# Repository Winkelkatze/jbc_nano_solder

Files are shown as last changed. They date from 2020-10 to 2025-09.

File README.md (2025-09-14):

# JBC Nano Solder
DIY controller for JBC Nano (NT115) hand piece and C115 tips.

This project can be found on Hackaday: https://hackaday.io/project/175580-diy-jbc-nano-controller

JBC makes awesome high-end soldering irons for professional use. The stations are quite expensive (especially the Nano system), however the tips and hand pieces are reasonably priced for hobby users. Therefore building controllers for these became kind of a sport among DIYers.

## State of the project
This project is in a working state, but is not actively worked on and there are a few unsolved issues, that can lead to the tip overheating if things go wrong. The issues stem from using a low-side gate driver to drive a P-channel FET on the high side. This causes the default state to be **ON**, which in turn means, the heater is powered when there is no signal telling it otherwise. This happens, if the CPU is in RESET or has no power.
Make sure to always disconnect the iron when flashing the firmware, debugging or making changes to the hardware.
**As a mitigation, consider adding a pull-up resistor to the gate driver input.**

## Why Nano and not T245/T210 as everyone else?
The JBC NT115 soldering iron is amazing, it's quite compact, has a slim cable and the grip-to-tip distance is really small. It's meant for super fine-pitched SMT parts, yet if you combine it with a larger tip, its powerful enough for most soldering needs. So, despite being a high precision tool, it is still use-able as a general purpose soldering iron.

Also, there is no real point in DIYing a controller for the larger irons from scratch, since there are already heaps of projects on the internet.

## Differences to the T245/T210
Both have similar tips with the heater and thermocouple embedded directly in the tip.
### Plug
The most obvious difference is the plug, this immediately suggests that there are some more fundamental difference between the two irons.
### Voltage
The NT115 system is designed for a much lower voltage. If I remember correctly, NT115 uses about 9V while T245 is more 20ish. Not sure how bad too much power is, but overloading the tip by a factor of 4 doesn't sound good. For reference, the C115 heaters have a (hot) resistance of about 5 Ohms, which would result in ~16W at 9V, so that's quite close to the nominal 15W of the tips.
### Heater and thermocouple are in series
Despite the cable having three wires and the tip having three contacts, two of the contacts seem to be internally connected inside the tip. So, the only way to power the heater is through the thermocouple. This sounds odd at first, but that's just how it it...

## Status of this project
Everything works pretty well, the heat-up times are JBC-like fast and the temperature is quite stable. I don't know the exact characteristics of the thermocouple, but from tests, I assume the sensitivity is about 9uV/K. It doesn't matter that much, since the temperature you need for a job depends highly on the tip and the job anyway anyway. The hardware supports to measure the supply voltage, but I'm not using it right now.
### Under-voltage self destruct
One issue with the current hardware is a potential self-destruct scenario, if the supply voltage is too low. Since I'm using a low-side driver to drive a high-side P-Channel FET, the undervoltage lockout (about 4V) of the driver will force the FET ON when the supply voltage is too low. This may cause the tip or the mosfet to overheat. So, be careful with the choice of power supply.

## Building the firmware
To build the firmware, you will need the ARM toolchain on your machine. I have only tested the build on Linux, so not sure how this would work on other OSes.
### Clone repo and submodules
```
git clone https://github.com/Winkelkatze/jbc_nano_solder.git
cd jbc_nano_solder
git submodule init
git submodule update
```
### Build libopencm3
```
cd firmware/libopencm3
make
```
### Build the firmware
```
cd firmware
make
```
### Flashing the firmware
You can either use your preferred tool to flash the .elf manually or, if you have openocd installed and the controller connected with a STLINK, the firmware can be flashed with
```
make flash
```

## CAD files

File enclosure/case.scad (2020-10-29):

$fn=32;

mounting_cone_hole = 0.5;
mounting_cone_hole_depth = 4;
mounting_cone_r_top = 2;
mounting_cone_r_bottom = 3;
mounting_cone_height = 8;

mounting_holes = [
[25.9, 25.1],
[35.8, 25.1],
[67.6, 25.1],
[25.1, 47.0],
[40.6, 45.2],
[26.9, 68.3]];

encoder_pos = [30.2, 35.9];
encoder_hole_r = 3.5;

disp_cutout = [25.5, 9];
disp_pos = [11 + 3 + encoder_pos[0], encoder_pos[1] - 0.8 - disp_cutout[1]/2];

stand_nuts = [[63, 35], [73, 45]];
stand_nuts_hole = 1.5;
stand_nuts_extra_strength = 1;
stand_nuts_socket_height = 2.5;
stand_nuts_socket_size = 3.1;
stand_nuts_socket_brim = 2;

front_plate_width = 2;
sides_width = 2;
sides_height = 35;
sides_offset = front_plate_width;

pcb_offset = [22.9, 22.6];
pcb_size = [70.9, 71.6] - pcb_offset;
// top, right, bottom, left
pcb_spacing = [4, 30, 1, 1];

connector_holes = [
[10, 23, 7.5/2],
[35, 23, 10/2]];

bottom_overlap = 2.5;
bottom_height = 1.5;
bottom_overlap_width = 3;

holder_mount_distance = stand_nuts[1] - stand_nuts[0];
holder_base_size = 20;
holder_base_height = 10;
holder_base_wire = 0.4;
holder_tower_r = 4;
holder_tower_height = 85;
holder_tower_hole = 1.5;
holder_screw_offset = 2;
holder_screw_head = 2.8;

holder_arm_height = 9.5;
holder_arm_length = 30;
holder_arm_tower_overlap_r = 2;
holder_arm_tower_overlap_h = 6;
holder_arm_circle = 8;
holder_arm_circle_inner_t = 5.7;
holder_arm_hole = 4;
holder_arm_wire = 0.8;
holder_arm_wire_hor = 0.5;


outer_a = [
        -pcb_spacing[3] - sides_width,
        -pcb_spacing[0] - sides_width];
    
outer_size = [
    pcb_size[0] + pcb_spacing[3] + pcb_spacing[1] + sides_width * 2,
    pcb_size[1] + pcb_spacing[2] + pcb_spacing[0] + sides_width * 2];


module base_plate()
{
    translate([-pcb_spacing[3], -pcb_spacing[0], 0])
    {
        cube([
            pcb_size[0] + pcb_spacing[3] + pcb_spacing[1],
            pcb_size[1] + pcb_spacing[2] + pcb_spacing[0],
            front_plate_width]);
    }
}

module mountings()
{
    translate([-pcb_offset[0], -pcb_offset[1], front_plate_width])
    {
        for (hole = mounting_holes)
        {
            translate([hole[0], hole[1], 0])
            {
                difference()
                {
                    cylinder(mounting_cone_height,
                             mounting_cone_r_bottom,
                             mounting_cone_r_top);
                    translate([
                        0,
                        0,
                        mounting_cone_height - mounting_cone_hole_depth])
                    {
                        cylinder(mounting_cone_hole_depth,
                                 mounting_cone_hole,
                                 mounting_cone_hole);
                    }
                }
            }
        }
    }
}

module display_cutout()
{
    translate([-pcb_offset[0] + disp_pos[0],
               -pcb_offset[1] + disp_pos[1],
               0])
    {
        cube([disp_cutout[0],
              disp_cutout[1],
              front_plate_width]);
    }
}

module encoder_hole()
{
    translate([-pcb_offset[0] + encoder_pos[0],
               -pcb_offset[1] + encoder_pos[1],
               0])
    {
        cylinder(h=front_plate_width,
                 r1=encoder_hole_r,
                 r2=encoder_hole_r);
    }
}

module sides()
{
    translate([outer_a[0], outer_a[1], sides_offset])
    {
        cube([outer_size[0], sides_width, sides_height]);
        cube([sides_width, outer_size[1], sides_height]);
    }
    
    translate([outer_a[0], outer_a[1] + outer_size[1] - sides_width, sides_offset])
    {
        cube([outer_size[0], sides_width, sides_height]);
    }
    
    translate([outer_a[0] + outer_size[0] - sides_width, outer_a[1], sides_offset])
    {
        cube([sides_width, outer_size[1], sides_height]);
    }
}

module connector_holes()
{
    translate([outer_a[0] + outer_size[0] - sides_width, 0, front_plate_width])
    {
        for (hole = connector_holes)
        {
            translate([0, hole[0], hole[1]])
            {
                rotate([0,90,0])
                {
                    cylinder(sides_width, hole[2], hole[2]);
                }
            }
        }
    }
}

module stand_nuts_pos()
{
    for (s = stand_nuts)
    {
        translate([s[0], s[1], front_plate_width])
        {
            cylinder(h = stand_nuts_socket_height, r = stand_nuts_socket_size + stand_nuts_socket_brim + stand_nuts_extra_strength, $fn=6);
        }
    }
}

module stand_nuts_neg()
{
    for (s = stand_nuts)
    {
        translate([s[0], s[1], 0])
        {
            cylinder(h = front_plate_width + stand_nuts_extra_strength, r = stand_nuts_hole);
        }
        translate([s[0], s[1], front_plate_width + stand_nuts_extra_strength])
        {
            cylinder(h = stand_nuts_socket_height, r = stand_nuts_socket_size, $fn=6);
        }
    }
}

module base()
{
    hull()
    {
        base_plate();
        translate([outer_a[0], outer_a[1], sides_offset - 0.01])
        {
            cube([outer_size[0], outer_size[1], 0.01]);
        }
    }
}

module front_plate()
{
    difference()
    {
        union()
        {
            base();
            stand_nuts_pos();
        }
        display_cutout();
        encoder_hole();
        stand_nuts_neg();
    }
    
    
    mountings();
    difference()
    {
        sides();
        connector_holes();
    }
}

module bottom_plate()
{
    
    translate([-pcb_spacing[3], -pcb_spacing[0], 0])
    {
        difference()
        {
            cube([
                pcb_size[0] + pcb_spacing[3] + pcb_spacing[1],
                pcb_size[1] + pcb_spacing[2] + pcb_spacing[0],
                bottom_overlap]);
            translate([bottom_overlap_width, bottom_overlap_width, 0])
            {
                cube([
                pcb_size[0] + pcb_spacing[3] + pcb_spacing[1] - bottom_overlap_width * 2,
                pcb_size[1] + pcb_spacing[2] + pcb_spacing[0] - bottom_overlap_width * 2,
                bottom_overlap]);
            }
        }
    }
    
    translate([outer_a[0], outer_a[1], -bottom_height])
    {
        cube([outer_size[0], outer_size[1], bottom_height]);
    }
}

module holder_tower()
{
    hull()
    {
        cube([holder_base_size, holder_base_size, 0.01]);
        translate([holder_base_size / 2, holder_base_size / 2, holder_base_height])
        {
            cylinder(h=0.01, r=holder_tower_r);
        }
    }
    translate([holder_base_size / 2, holder_base_size / 2, holder_base_height])
    {
        cylinder(h=holder_tower_height, r=holder_tower_r);
    }
}

module holder_tower_neg()
{
    translate([holder_base_size / 2, holder_base_size / 2, 0])
    {
        cylinder(h=(holder_base_height + holder_tower_height), r=holder_tower_hole);
        translate([-holder_mount_distance[0] / 2, -holder_mount_distance[1] / 2, 0])
        {
            cylinder(h=holder_screw_offset, r=stand_nuts_hole);
            translate([0, 0, holder_screw_offset])
            {
                cylinder(h=holder_base_height, r=holder_screw_head);
            }
        }
        translate([holder_mount_distance[0] / 2, holder_mount_distance[1] / 2, 0])
        {
            cylinder(h=holder_screw_offset, r=stand_nuts_hole);
            translate([0, 0, holder_screw_offset])
            {
                cylinder(h=holder_base_height, r=holder_screw_head);
            }
            
            k = stand_nuts_hole / sqrt(2);
            translate([-k, -k, 0])
            {
                cylinder(h=holder_screw_offset, r=holder_base_wire);
            }
        }
        rotate([0, 90, 45])
        {
            cylinder(h=norm(holder_mount_distance / 2), r=holder_base_wire);
        }
    }
}

module holder()
{
    difference()
    {
        holder_tower();
        holder_tower_neg();
    }
}

module holder_arm_pos()
{
    hull()
    {
        cylinder(h=holder_arm_height, r=(holder_arm_tower_overlap_r + holder_tower_r));
        translate([holder_arm_length, 0, 0])
        {
            cylinder(h=holder_arm_height, r=holder_arm_circle);
        }
    }
}
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

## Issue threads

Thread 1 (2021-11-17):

question

hasulhasancevik, 2021-11-17:
hello, i want to try the project. I need help. Which compiler did you use? I tried cubemx and atollic but I'm getting a compile error.

Winkelkatze, 2021-11-17:
Indeed, there was an issue with the git submodules.
The issue should be fixed now and I added build instructions to the README.

Thanks for the feedback!

hasulhas, 2021-11-19:
Hello sir.  I added the new libraries, but I still get an error when compiling.  I guess I couldn't.  Is it possible to export the project again?  I am using stm32cubeid.

Winkelkatze, 2021-11-20:
I didn't use STM32CubeIDE or the STM32CubeMX for this project. Its built with libopencm3 and uses a Makefile for building. Not sure if its possible to build a plain Makefile project through the STM32CubeIDE.
But if you simply follow the build instructions you won't need the CubeIDE anyway.

hasulhas, 2021-11-20:
thank you very much for your help.  today i installed ubuntu program with virtual machine.  I created the *.elf file.  and I think it will be enough to write this file to the chip.

hasulhas, 2021-11-23:
Hello, I'm bothered again.  Does this project have auto sleep mode?

hasulhas, 2021-12-15:
Hello sir.  I built the circuit.  but the screen keeps coming and going.  and the encoder is not working.  What is the problem? can you help me?

https://user-images.githubusercontent.com/56305854/146142587-3e44a64a-28d1-4c33-b0aa-b25b265cdcbe.MOV

Winkelkatze, 2021-12-20:
This very much looks like a power supply issue. If you have one, you should check the 3.3V rail with an oscilloscope.

Have you connected a soldering iron in your test setup? Could be that the current draw brings the power supply to its knees.

hasulhas, 2021-12-21:
Thanks for your help.  screen problem solved.  but I could not run the encoder.  the opamp is connected but I did not power it.  I guess it's not related to that.  Sorry for tiring you.
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

https://user-images.githubusercontent.com/56305854/146919004-94443d6b-5d04-4af3-85bb-d3c4ca2760cd.MOV

Winkelkatze, 2021-12-21:
No worries :)
About the encoder: Not sure about that, but in the first video it looks like you accidentally swapped the encoder GND and 3.3V, this would explain why the switch is not working. Normally a press on the encoder *should* get you to the main screen.
If the encoder connections are correct and it still doesn't work, try to short PA6 to GND with a jumper wire.
About the rotary part, are you sure the encoder is a normal A/B encoder? On the PCB the pins are labeled as CLK and DT which suggest a different type of encoder.

hasulhas, 2021-12-21:
yes I tried without encoder.  with tweezers.  The menu did not come.  I guess I don't see a small detail :)

Winkelkatze, 2021-12-21:
Hmm, that's strange. The IOs for the encoder are pulled up by the micro using the internal pull-up resistors. So a very simple test would be to measure the voltage at these pins when there is nothing connected to them and the micro is running normally ("Default cfg loadad" screen on the display). If everything is working, your multimeter should read something between 2.5 and 3.3 volts.

If there is voltage on those pins, you could also try to measure the current sourced by them to verify the pull-up is working normally. Measuring in mA mode between the pin and GND should read about 100uA (0.1mA)

hasulhas, 2021-12-22:
Hello sir.  I made the measurements, it's on the 3.3v pa6 pin.  current 0.07mA.  There is an 8Mhz crystal on the circuit, is it normal?

Winkelkatze, 2021-12-22:
I just looked through the code. There is really not much that can go wrong between the screen you are stuck at and the main screen. Just to be sure, you connected the pin to ground *and* released it again, right? :)
One potential candidate would be the eeprom write never going through. Can you add a "return;" in source/eeprom_i2c.c at the beginning of eeprom_write (so in line 66)?

Besides that, do you have a serial adapter? The controller should be sending out some data on the TXD pin at 115200 baud. Might be helpful to see whats going on there

hasulhas, 2021-12-22:
sir, i am compiling via virtual drive for linux.  maybe there is an error.  Can you send the build.elf file?

Winkelkatze, 2021-12-23:
I doubt this is a problem with your toolchain, but I attached a build anyway. This also includes a build where the eeprom write is disabled. I also added some more debug output, so it would be very helpful, if you could check the serial output.
[firmware.zip](https://github.com/Winkelkatze/jbc_nano_solder/files/7769144/firmware.zip)

hasulhas, 2021-12-23:
thank you very much sir.  build.elf still didn't work but no eeprom.elf did.  As a result, is my eeprom incompatible?
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

Winkelkatze, 2021-12-23:
So it was a problem with the eeprom.
I re-checked my code and found some potential problems with the eeprom write routine. Can you try again with the new version?

hasulhas, 2021-12-24:
thank you sir.  the new build worked.  I'll try connecting a soldering iron.  I will let you know the latest.

hasulhas, 2021-12-24:
works great.  thank you very much.  excellent software and hardware.  How can I do the calibration?  It heats up to about 140 degrees low.  For example, I want to melt the solder at 180 degrees.

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

Winkelkatze, 2021-12-24:
It depends a bit on what handpiece / tip you are using. I designed that with the JBC nano tips in mind, which have a thermocouple sensitivity of about 9 uV/K. Most other soldering irons use thermocouples with a higher output voltage.

Minor changes can be compensated by changing the calibration value in the menu. The allowed range is 7.5-11uV/K. The limits for the range are hard-coded, but can be changed in the config.c file. You may would also have to change the PANIC_CUTOFF_ADC_VALUE (in main.c) to avoid the over-temperature shutdown (ERROR T HIGH).

But keep in mind, that the amplifier gain is set to work with these low-sensitivity thermocouples. The gain is 501, so this limits the maximum thermocouple voltage to about 6.5 mV. So for a different thermocouple you may have change the amplifier gain and also the value in the software.

hasulhas, 2022-01-21:
hello master.  The soldering iron was great, thank you very much.  Can you write a little code for me?  “1 second boot logo”

https://user-images.githubusercontent.com/56305854/150538077-2b62a775-fc5c-412c-9206-80cd500d1c95.MOV

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

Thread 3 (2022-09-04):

programing step

warehouseElc, 2022-09-04:
i want to ask about programing method you used,
what programing software and hardware. of course the OS are you using ?
i'm not familar with stm32, but i know the basic.

Winkelkatze, 2022-09-04:
This project runs on a STM32F030, this is one of the smallest (if not the smallest) STM32 controller. The software is based on libopencm3, which is a more compact alternative to the official CubeHAL from ST.

About the *how* I developed the firmware, I use the "classic" approach by using a text editor for writing code and a Makefile for compiling everything using the arm toolchain (arm-none-eabi-gcc). I've only tested this on Linux, but I might be possible to do the same thing with Cygwin or WSL on Windows.
The programmer itself is one of these cheap as STLink clones which I use together with OpenOCD. And sometimes I also use the embedded serial bootloader for flashing STM32.

warehouseElc, 2022-09-04:
thanks for replying my post, i just finish board assembley still waiting for handle and tip.
a bit confuse about selecting compiler, what should i buy ?
should it work with a generic stlink ?

if any exist video will help me very much. one more question, the At24cs01 is out of stock I can't find it, so i replace with at24c01, i confuse about pin a0,a1,a2 and i'm not connect it to anywhere.

Winkelkatze, 2022-09-05:
I don't know of any video to help you, but what you will need is the ARM toolchain (arm-none-eabi-gcc), git and make. I'm sure you can find install instructions for this on the internet.
Then you can simply follow the "Building the firmware" instructions from my README. This will produce a .elf file which can be flashed to the controller by various means. If you also install openocd it should be as simple as running "make flash" but there is also plenty information available how to get a .elf to your controller.

About the EEPORM, the at24c01 one should be fully compatible. I'm a bit confused about the address pins, did you change the footprint to a 8 pin variant? If so, the address pins need to be tied to ground. The 5 pin variant doesn't have these pins and they are bonded to ground internally.

warehouseElc, 2022-09-06:
i found some tutor in internet, hope that methode will working, first we need to compile to elf and secondly upload to the board right ?
is there any button i have to press before or during upload ?

i didnt make any changes of footprint, just making an adapter with protoboard and put in at oled pinout in series with oled display because it use same pinout i think it should work.

Winkelkatze, 2022-09-06:
Yes, its easiest to do this as two separate steps. For flashing, if you use the STLINK, you don't need to press any button.

If you decide to use the serial bootloader, you first need to bring the controller into the boor mode by holding the BOOT button while it starts. So press and hold boot while you also press RESET briefly. You can then use "stm32flash" (https://sourceforge.net/p/stm32flash/wiki/Home/) to write the firmware to the controller. If you choose this approach, don't forget to convert the .elf into binary first with "arm-none-eabi-objcopy -O binary firmware.elf firmware.bin".

Cool solution for the eeprom by the way :)

warehouseElc, 2022-09-06:
I think the first methode is more easy, i was install like you said and confirm that was a build.elf after i build the firmware. at openOCD command i test make flash and its says no stlink detect.
unfortunately i don't have stlink, maybe i'll buy a cheap clone one, so before thats arrive i still have a time to learn the firmware.

Winkelkatze, 2022-09-07:
Cool that it works so far.

About the buzzer, this should be possible since there is still about 600 bytes free.

warehouseElc, 2022-09-13:
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
update : its work but i dont know how to test eeprom, a bit confuse about datasheet at24c01n, some have address pin and the other said no internal conection. so i leave it open
any idea how to test it ?

Winkelkatze, 2022-09-14:
Nice board :)

About the EEPROM address pins, normally they should be tied to ground. But if it also works like this, they may have internal pull-downs so you could also let them floating. As long as its keeping the settings and the last set temperature, the eeprom is working fine.

Winkelkatze, 2022-09-14:
I just realized, that one value from the schematic was wrong. R5 should be 5K instead of 10K, to set the gain for the thermocouple to 501 (instead of the original 1001). I also added this value as a constant in main.c ("THERMOCOUPLE_GAIN").

If you don't have a 5k resistor at hand, you can just stack two 10k resistors, or use a slightly different value and adjust the THERMOCOUPLE_GAIN in main.c

warehouseElc, 2022-09-21:
today my Chinese 115 it has 3,1 ohm resistance.
it hot like it should. i didn't understand how the code works, i set to 110c it raise to 160c and go to 110. is it working correctly ?
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

Winkelkatze, 2022-09-21:
It should not do that. My build does not overshoot more than 5 degrees when turning on.
I see two possible causes for such behavior:

Cause 1: The outlier detection code for filtering the measured temperature is causing problems.
Maybe for some reason the temperature measurement in your setup is very noisy.
You can test that by adding a "return true;" to the first line of the "outlier_detection" function (Line 519 in main.c) The temperature control should still work like this, but the displayed temperature may be a bit unstable and the out-of-stand idle detection may not work.

Cause 2: The tip you are using has a much worse thermal coupling between the heater and the sensor.
All my tips react almost immediately to power changes. Meaning if the heater is turned OFF, the temperature immediately stops rising. It is possible, since you are using some non-original tips that the thermocouple lags behind the heater, which makes the control highly unstable. Increasing the "Reg wnd size" (In the Menu, in the "Heater controller" settings) to a higher value may help. This will slightly degrade the response to temperature changes though.

If you want to experiment with different control algorithms, the controller is implemented in "dma1_channel1_isr" (main.c)

warehouseElc, 2022-09-21:
thanks i'll try your guide.
oh yes forget to tell i was lazy to hook up with a good smps, so i connect it to linear ps, maybe that cause the trouble.

warehouseElc, 2022-09-22:
i think is not ps issue, like you said the noise is too high.

noise when start up.
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

noise when temp is stable.
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

Winkelkatze, 2022-09-24:
The only real way to solve that issue is by adjusting the controller. At the moment, the control algorithm is mainly a proportional approach with a small integral component.
I did it that way, since it worked perfectly for me. The tips you are using make the control more difficult, but I'm almost certain by implementing a proper PID control this could be solved.

Winkelkatze, 2022-09-24:
If you don't want to dig into controller design, I have a few alternative options for you which you might want to try:

Reducing the power limit ("Heater controller" -> "Max PWM duty") will definitely help.

You could try is to increase the P controllers window (Reg wnd size) even more and also increase the I controllers limit (Int. ofs limit). You need to adjust the limits in menu.c for that.
This makes the controller less aggressive which should solve overshooting.

One general remark though, even with the best control algorithms, the delay caused by the tip will always result in a slower response time and worse performance while soldering.

warehouseElc, 2022-09-24:
i already did incrase the pwm periode about 25ms and incrase the reg wnd size in main.c after the test yesterday, now no more over shoot, thanks for spending your time in this thread.
it's a great controller for nano and also good job for the hardware and software.
one issue with encoder, it jump 2 step
should it work if i fix debounce at input.c incrase or decrease the tick ?

Winkelkatze, 2022-09-26:
No, its a PI controller without differential (D) part. You are correct, that the "Int. ofs" (short for Integral offset) is the integral part. However, this is not implemented as a traditional P-I controller where P gets zero during stable operation. The 'I' part rather slightly offsets the target for the P controller so we reach the target.
But yes, "reg wnd size" (Regulation window size) sets the inverse gain for the P controller, so P = 1 / "reg wnd size".

About the encoder issue, seems like there are different types of encoders. The one I use makes two signal steps (phase changes) per physical / haptic step (detent). So that's why I implemented it this way. Maybe your encoder works differently. Could also be a contact bouncing issue, so you can also try to increase the debounce value.

warehouseElc, 2022-09-27:
now i get it, i've to calibrate with that way.

thanks, i'll try incrasing debounce value.
pin uart its for programing or debug ? or both function will work ? cause i didnt see any serial out at the firmware.

Closed 2022-11-28.

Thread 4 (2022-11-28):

improve with a buzzer

warehouseElc, 2022-11-28:
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

hello, i try to mod a firmware but i can't get it.
need help for my project  i still use Chinese c210 controller for this build, my plan is attach t-210 tips to this controller and i think it will work, just need to calibrate it.

what i need just a buzzer. the code is too complicated for me and i didn't know what pinout should use.
i didnt use uart port maybe you can change it to a buzzer for me if you're on a free hand, i'll be appreciated that.

Winkelkatze, 2022-12-07:
Sure, you could re-purpose the uart pins. They are even timer outputs, so this could be used to generate the waveform for the beeper (for those without inbuilt electronics).
Another option would be to leave out the crystal, since this is not exactly required in this application anyway. I just included that, since I always do :)

But, I honestly don't see any reason why a soldering controller would need a beeper...
So, I'm sorry, but if you want to have one, you have to implement it yourself. This should be really straight-forward by just reading a bit the libopencm3 documentation.

I could help you if you have any specific questions though :)

warehouseElc, 2022-12-08:
the reason why i need a buzzer is for feedback when its ready or error even it is on seat, because i cant always look to display when working on fragile component.
i try to implement it by myself, but i didn't test because i'm not sure will work, the timer confuse me a lot.

first i need to know, what timer in rx or tx pin can be used ?
i read in datasheet its run on different timer, should i use timer for that pin, or i can just used any timer available?

warehouseElc, 2022-12-20:
hello again,
today i was destroy my tip by disconnect the 3v supply and the mosfet stays on.
any idea how to force the mosfet off even no signal from mcu to the gate ? may be some pull down resistor i guess

hasulhas, 2024-01-10:
> hello again, today i was destroy my tip by disconnect the 3v supply and the mosfet stays on. any idea how to force the mosfet off even no signal to the gate ? may be some pull down resistor i guess

I had the same problem. Did you solve the problem?

warehouseElc, 2024-01-10:
nothing, just never cut any logic voltage. the way to turn on/off modul by cuting main voltage. now we have issue with over temp and the solder cool down.

hasulhas, 2024-01-11:
> nothing, just never cut any logic voltage. the way to turn on/off modul by cuting main voltage. now we have issue with over temp and the solder cool down.

added 10k resistor, between heater_on and VDC. problem solved.

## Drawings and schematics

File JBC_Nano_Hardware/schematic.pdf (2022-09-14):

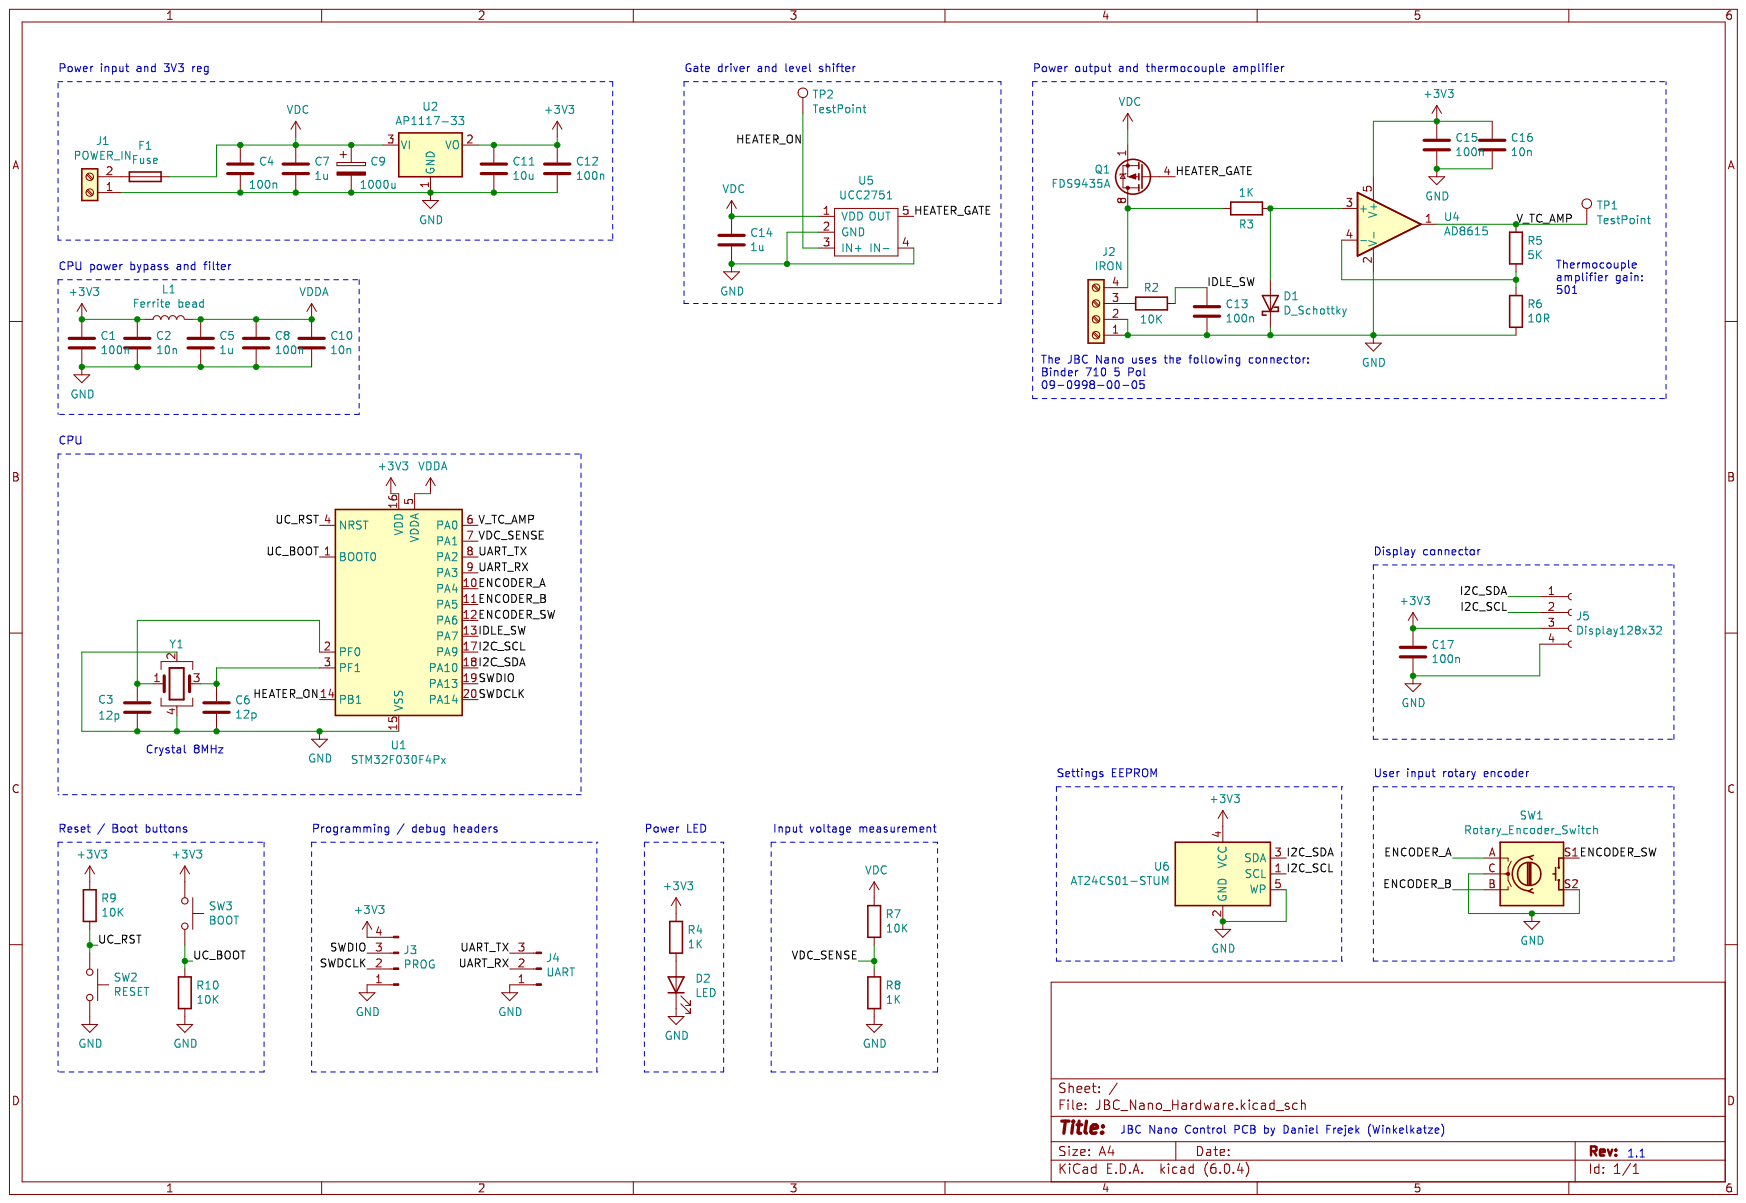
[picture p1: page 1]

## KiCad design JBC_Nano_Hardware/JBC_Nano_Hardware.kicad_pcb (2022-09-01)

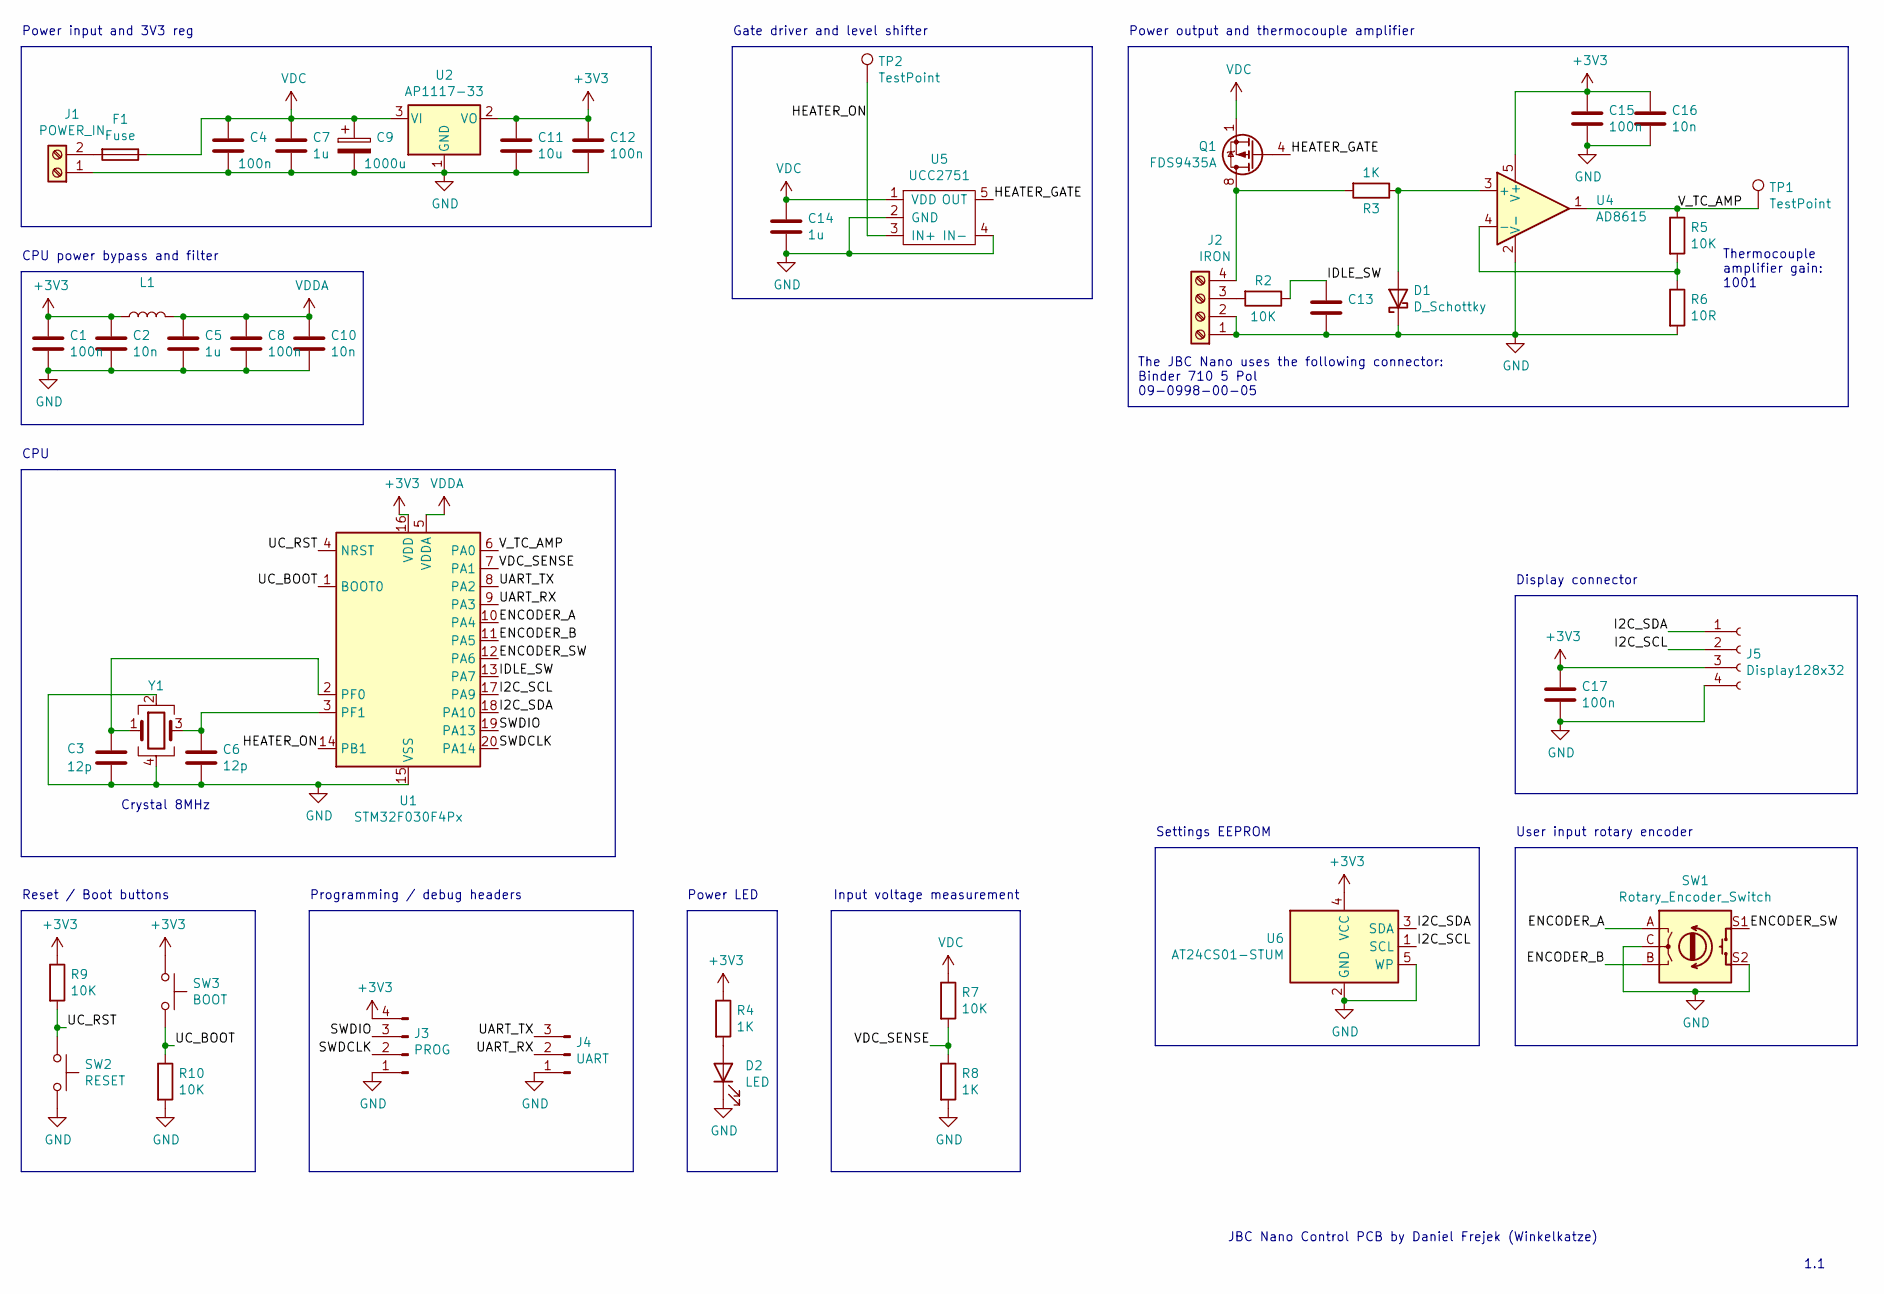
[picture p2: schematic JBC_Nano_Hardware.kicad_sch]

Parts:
C1, C4, C8, C12, C15, C17: 100n; C_0603_1608Metric
C2, C10, C16: 10n; C_0603_1608Metric
C3, C6: 12p; C_0603_1608Metric
C5, C7, C14: 1u; C_0603_1608Metric
C9: 1000u; CP_Radial_D10.0mm_P3.50mm
C11: 10u; C_0603_1608Metric
C13: C_0603_1608Metric
D1: D_Schottky; D_0603_1608Metric
D2: LED; LED_0603_1608Metric_Castellated
F1: Fuse; Fuseholder_Cylinder-5x20mm_Schurter_0031_8201_Horizontal_Op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
J1: POWER_IN; TerminalBlock_bornier-2_P5.08mm
J2: IRON; TerminalBlock_bornier-4_P5.08mm
J3: PROG; PinHeader_1x04_P2.54mm_Vertical
J4: UART; PinHeader_1x03_P2.54mm_Vertical
J5: Display128x32; PinSocket_1x04_P2.54mm_Vertical
L1: L_0805_2012Metric
Q1: FDS9435A; SOIC-8_3.9x4.9mm_P1.27mm
R2, R5, R7, R9, R10: 10K; R_0603_1608Metric
R3, R4, R8: 1K; R_0603_1608Metric
R6: 10R; R_0603_1608Metric
SW1: Rotary_Encoder_Switch; RotaryEncoder_Alps_EC12E-Switch_Vertical_H20mm
SW2: RESET; SW_SPST_B3U-1000P
SW3: BOOT; SW_SPST_B3U-1000P
TP1, TP2: TestPoint; TestPoint_Pad_D1.5mm
U1: STM32F030F4Px; TSSOP-20_4.4x6.5mm_P0.65mm
U2: AP1117-33; SOT-223-3_TabPin2
U4: AD8615; TSOT-23-5
U5: UCC2751; SOT-23-5
U6: AT24CS01-STUM; SOT-23-5
Y1: Crystal_GND24; Crystal_SMD_EuroQuartz_MJ-4Pin_5.0x3.2mm

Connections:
+3V3: C1.1, C2.1, C11.1, C12.1, C15.1, C16.1, C17.1, J3.4, J5.3, L1.1, R4.1, R9.1, SW3.1, U1.16 (VDD), U2.2 (VO), U4.5 (V+), U6.4 (VCC)
/ENCODER_A: SW1.A, U1.10 (PA4)
/ENCODER_B: SW1.B, U1.11 (PA5)
/ENCODER_SW: SW1.S1, U1.12 (PA6)
/HEATER_GATE: Q1.4 (G), U5.5 (OUT)
/HEATER_ON: TP2.1, U1.14 (PB1), U5.3 (IN+)
/I2C_SCL: J5.2, U1.17 (PA9), U6.1 (SCL)
/I2C_SDA: J5.1, U1.18 (PA10), U6.3 (SDA)
/IDLE_SW: C13.1, R2.1, U1.13 (PA7)
/SWDCLK: J3.2, U1.20 (PA14)
/SWDIO: J3.3, U1.19 (PA13)
/UART_RX: J4.2, U1.9 (PA3)
/UART_TX: J4.3, U1.8 (PA2)
/UC_BOOT: R10.1, SW3.2, U1.1 (BOOT0)
/UC_RST: R9.2, SW2.1, U1.4 (NRST)
/VDC_SENSE: R7.2, R8.1, U1.7 (PA1)
/V_TC_AMP: R5.1, TP1.1, U1.6 (PA0), U4.1
GND: C1.2, C2.2, C3.2, C4.2, C5.2, C6.2, C7.2, C8.2, C9.2, C10.2, C11.2, C12.2, C13.2, C14.2, C15.2, C16.2, C17.2, D1.1 (K), D2.1 (K), J1.1, J2.1, J2.2, J3.1, J4.1, J5.4, R6.2, R8.2, R10.2, SW1.C, SW1.S2, SW2.2, U1.15 (VSS), U2.1 (GND), U4.2 (V-), U5.2 (GND), U5.4 (IN-), U6.2 (GND), U6.5 (WP), Y1.2, Y1.4
unnamed: C3.1, U1.2 (PF0), Y1.1
unnamed: C6.1, U1.3 (PF1), Y1.3
unnamed: D1.2 (A), R3.1, U4.3 (+)
unnamed: D2.2 (A), R4.2
unnamed: F1.2, J1.2
unnamed: J2.3, R2.2
unnamed: J2.4, Q1.5 (D), Q1.6 (D), Q1.7 (D), Q1.8 (D), R3.2
unnamed: R5.2, R6.1, U4.4 (-)
VDC: C4.1, C7.1, C9.1, C14.1, F1.1, Q1.1 (S), Q1.2 (S), Q1.3 (S), R7.1, U2.3 (VI), U5.1 (VDD)
VDDA: C5.1, C8.1, C10.1, L1.2, U1.5 (VDDA)

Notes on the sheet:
Crystal 8MHz
JBC Nano Control PCB by Daniel Frejek (Winkelkatze)
Reset / Boot buttons
Gate driver and level shifter
CPU
Power LED
Power output and thermocouple amplifier
Thermocouple amplifier gain: 1001
1.1
Settings EEPROM
Input voltage measurement
CPU power bypass and filter
Programming / debug headers
Display connector
Power input and 3V3 reg
The JBC Nano uses the following connector: Binder 710 5 Pol 09-0998-00-05
User input rotary encoder

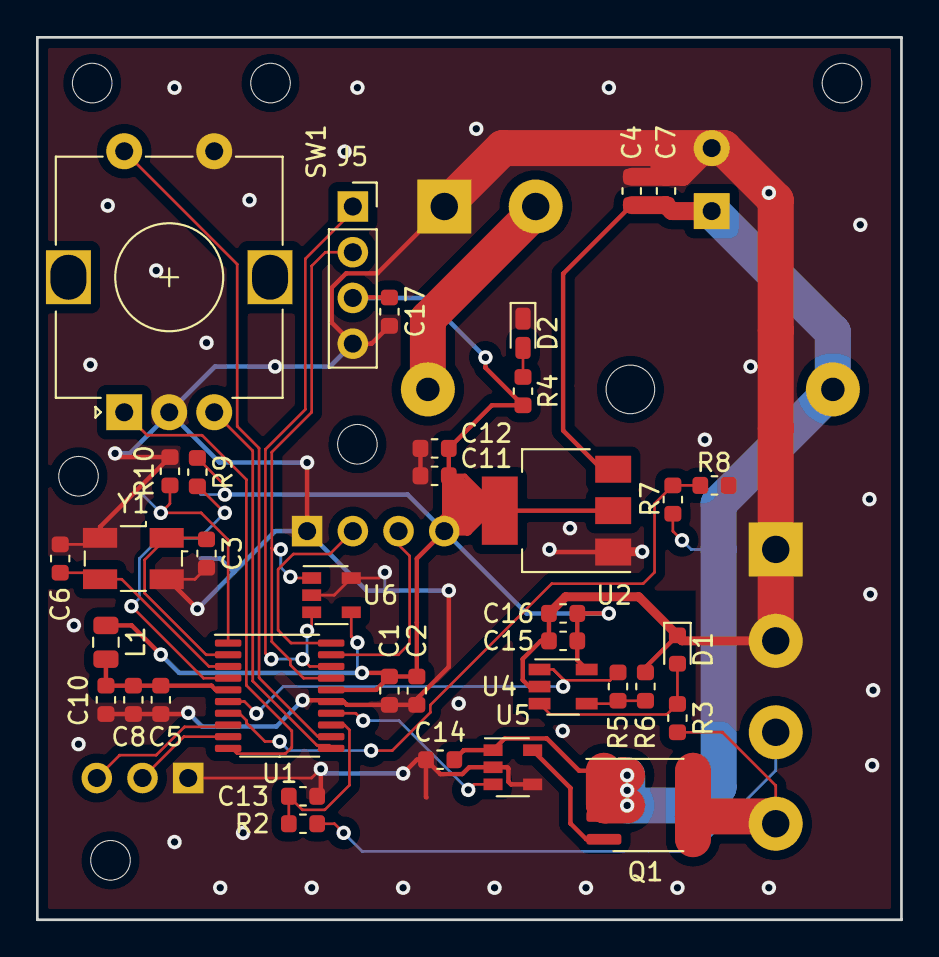
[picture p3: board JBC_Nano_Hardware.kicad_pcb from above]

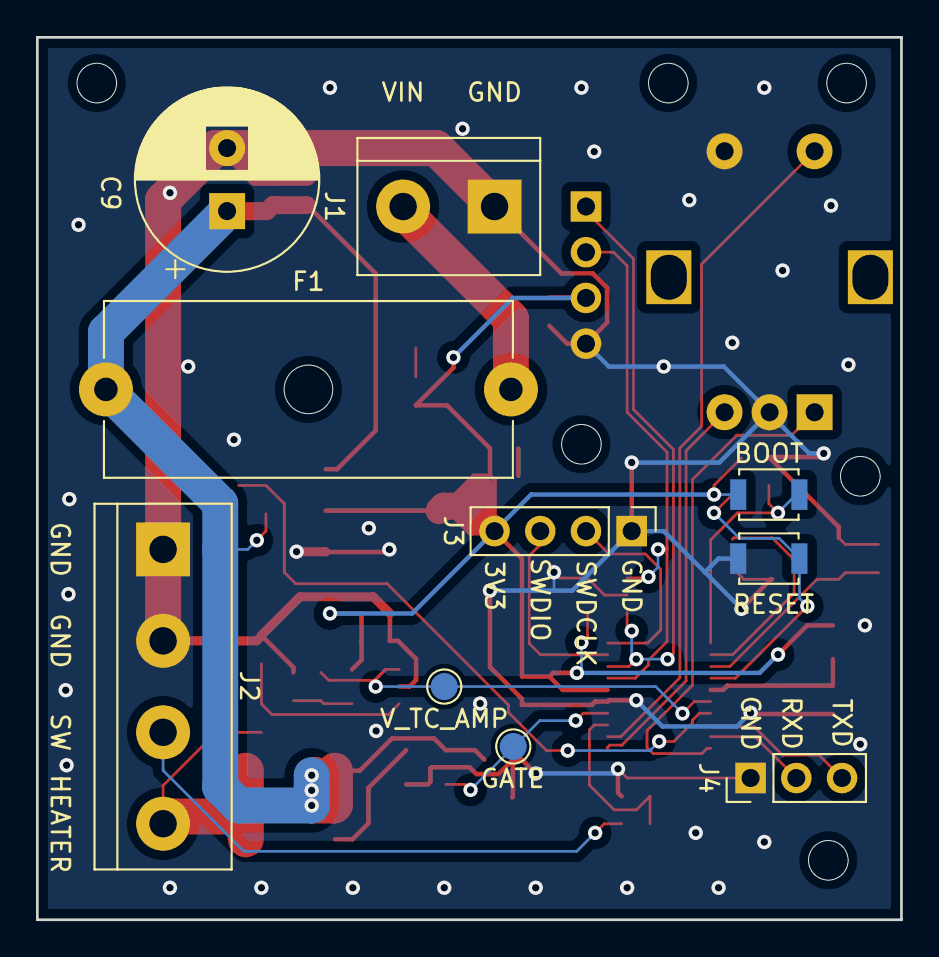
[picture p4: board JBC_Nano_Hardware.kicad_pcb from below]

Board: 2 copper layers, 48.0 x 49.0 mm, 47 parts (10 on the bottom side), 28 nets.

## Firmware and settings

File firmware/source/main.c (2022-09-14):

/*
 * MIT License
 *
 * Copyright (c) 2020 Daniel Frejek
 *
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
 * THE SOFTWARE IS PROVIDED "AS IS", WITHOUT WARRANTY OF ANY KIND, EXPRESS OR
 * IMPLIED, INCLUDING BUT NOT LIMITED TO THE WARRANTIES OF MERCHANTABILITY,
 * FITNESS FOR A PARTICULAR PURPOSE AND NONINFRINGEMENT. IN NO EVENT SHALL THE
 * AUTHORS OR COPYRIGHT HOLDERS BE LIABLE FOR ANY CLAIM, DAMAGES OR OTHER
 * LIABILITY, WHETHER IN AN ACTION OF CONTRACT, TORT OR OTHERWISE, ARISING FROM,
 * OUT OF OR IN CONNECTION WITH THE SOFTWARE OR THE USE OR OTHER DEALINGS IN THE
 * SOFTWARE.
 */

#include <libopencm3/stm32/rcc.h>
#include <libopencm3/stm32/gpio.h>
#include <libopencm3/stm32/usart.h>
#include <libopencm3/stm32/i2c.h>
#include <libopencm3/stm32/adc.h>
#include <libopencm3/stm32/dma.h>
#include <libopencm3/stm32/timer.h>
#include <libopencm3/stm32/iwdg.h>
#include <libopencm3/cm3/systick.h>
#include <libopencm3/cm3/nvic.h>
#include <libopencm3/stm32/exti.h>

#include <sys/types.h>
#include <stdlib.h>
#include <string.h>

#include "tinyprintf.h"
#include "ssd1306.h"
#include "eeprom_i2c.h"
#include "config.h"
#include "input.h"
#include "menu.h"
#include "gpio_conf.h"


#define HEATER_TIMER TIM3
#define HEATER_TIMER_PRESCALER 48 // 1us per tick, so max period is 65ms
#define HEATER_TIMER_OC TIM_OC4
#define HEATER_TIMER_OC_IRQ TIM_DIER_CC4IE

#define ADC_TRIGGER (3 << ADC_CFGR1_EXTSEL_SHIFT) // Timer3


// Gain of the thermocouple amplifier
#define THERMOCOUPLE_GAIN 501

#define TEMP_SAVE_INTERVAL 1000

// panic cutoff disables the heater until the mcu is reset
// this is at a relative temp of 440K assuming 9 uV/K and a VCC of 3.3V
#define PANIC_CUTOFF_ADC_VALUE ((440ULL * 9 * (THERMOCOUPLE_GAIN) * 4096) / 3300000) // ~430 C @ 3.3V

// Panic, if the temperature difference is below this for a given amount of time while the heater is on
// This should prevent overheating, if the tip is connected in the wrong polarity
#define PANIC_MINIMUM_TEMP_DIFF 20
#define PANIC_MINIMUM_TEMP_DIFF_TIMEOUT 1000

// If the measured supply voltage is not within this range, we set the error state
#define PANIC_MIN_SUPPLY_VOLTAGE  6000
#define PANIC_MAX_SUPPLY_VOLTAGE 15000

// Somehow we get some bad measurements (I think its interference from the display, but not sure...)
// In order to filter those, we add an "outlier detection"
// This works by calculating the average deviation from the average over the last measurements.
// If a measurement is more than THRESHOLD percent wrong, we skip controller cycle and use the average last value instead.
#define OUTLIER_DETECTION_WND 16
// Threshold should be at least 200, since this is what we expect for a monotonous increase
#define OUTLIER_DETECTION_THRESHOLD 230
// Minimum avg error (mK), this prevents generating lots of outliers when the temperature is stable
#define OUTLIER_DETECTION_MIN_AVG_ERR 2000

static void update_stby_state(void);
static bool outlier_detection(uint32_t value);

/*
 * Basic mode of operation
 * HEATING    |    DEAD_TIME    |    ADC_SAMPLE    | ...
 *            ^                 ^                  ^
 *        Timer OC   Timer update (adc trg)   ADC cplt int
 */

volatile uint32_t tickcounter = 0;


#define ADC_VALUE_VREF 0
#define ADC_VALUE_VDC  1
#define ADC_VALUE_TC   2
static volatile uint16_t adc_values[3];

// This is the panic shutdown
// Value is set to true, if the temperature exceeds the panic threshold
// It's never cleared, so device needs to be restart.
static volatile bool kill_heater = false;
static const char *err_reason = NULL;

// derived from period and max_pwm
static uint16_t heater_max_period;

static uint16_t temp_set;
static uint32_t temp_current1000;
static uint16_t controller_offset1000 = 0;
static uint32_t current_duty_smoothed = 0;
static uint32_t current_duty_lt_avg100 = 0;
static uint32_t temp_diff_panic_timer = 0;
static uint32_t outlier_detection_window[OUTLIER_DETECTION_WND] = {};
static size_t outlier_detection_index = 0;
static size_t outlier_detection_sum = 0;


static struct
{
	uint32_t idle_detect_timer;
	uint32_t timer;

	bool manual_off;
	bool off;
	bool stby;
	bool idle_sw;
} stby_state;



void sys_tick_handler(void)
{
	tickcounter++;
	input_update();
	update_stby_state();
}


void dma1_channel1_isr(void)
{
	// DMA interrupt from ADC DMA
	// only used for DMA1_TCIF
	dma_clear_interrupt_flags(DMA1, 1, DMA_TCIF);

	if (adc_values[ADC_VALUE_TC] > PANIC_CUTOFF_ADC_VALUE)
	{
		kill_heater = true;
		err_reason = "T HIGH";
	}

	uint16_t ts = temp_set;

	if (stby_state.off)
	{
		ts = 0;
	}
	else if (stby_state.stby && config.standby_temp < ts)
	{
		ts = config.standby_temp;
	}

	// thermocouple voltahe in 0.1uV
	uint32_t vtc_uv10 = (((33000000ULL / (THERMOCOUPLE_GAIN)) * ST_VREFINT_CAL) * adc_values[ADC_VALUE_TC]) / adc_values[ADC_VALUE_VREF] / 4096;

	// temperature in mK
	// Of course, our resolution isn't that high, but it makes our controller more stable if we use more precise values.
	uint32_t tc1000 = (1000 * vtc_uv10) / config.tc_v_per_deg;

	if (!kill_heater)
	{
		if (ts == 0 || tc1000 > PANIC_MINIMUM_TEMP_DIFF * 1000)
		{
			temp_diff_panic_timer = tickcounter;
		}
		else if ((tickcounter - temp_diff_panic_timer) > PANIC_MINIMUM_TEMP_DIFF_TIMEOUT)
		{
			kill_heater = true;
			err_reason = "T LOW";
		}

		uint32_t vdc = ((3300ULL * 11 * ST_VREFINT_CAL) * adc_values[ADC_VALUE_VDC]) / adc_values[ADC_VALUE_VREF] / 4096;
		if (vdc < PANIC_MIN_SUPPLY_VOLTAGE)
		{
			kill_heater = true;
			err_reason = "V LOW";
		}
		if (vdc > PANIC_MAX_SUPPLY_VOLTAGE)
		{
			kill_heater = true;
			err_reason = "V HIGH";
		}
	}

	tc1000 += config.tc_offset * 1000;

	uint16_t new_period = 0;

	// outlier detection
	if (outlier_detection(tc1000))
	{
		temp_current1000 = (temp_current1000 * 7 + tc1000) / 8;
		int err1000 = (int)(ts * 1000) - (int)tc1000;

		int int_adjust1000;
		if (err1000 > 0 && err1000 > config.controller_int_speed)
		{
			int_adjust1000 = config.controller_int_speed;
		}
		else if (err1000 < 0 && -err1000 > config.controller_int_speed)
		{
			int_adjust1000 = -(int)config.controller_int_speed;
		}
		else
		{
			int_adjust1000 = err1000;
		}

		if (int_adjust1000 > 0 && controller_offset1000 + int_adjust1000 > config.controller_int_limit * 1000)
		{
			controller_offset1000 = config.controller_int_limit * 1000;
		}
		else if (int_adjust1000 < 0 && controller_offset1000 < -int_adjust1000)
		{
			controller_offset1000 = 0;
		}
		else
		{
			controller_offset1000 += int_adjust1000;
		}

		err1000 += controller_offset1000;
		//printf("tc=%u, ts=%u, e=%i co=%u, ia=%i\n", tc1000/1000, temp_set, err1000, controller_offset1000, int_adjust1000);


		if (err1000 > config.controller_window * 1000)
		{
			// max power
			new_period = heater_max_period;
		}
		else if (err1000 > 0)
		{
			// (err / wnd) * max_period
			new_period = (err1000 * heater_max_period) / (config.controller_window * 1000);
		}
	}
	else if (!stby_state.off && ts > config.tc_offset)
	{
		// detected an outlier, so we just re-use the average
		new_period = current_duty_smoothed;
	}

	timer_set_oc_value(HEATER_TIMER, HEATER_TIMER_OC, new_period);

	current_duty_smoothed = ((current_duty_smoothed * 63) + new_period) >> 6;
	current_duty_lt_avg100 = ((current_duty_lt_avg100 * 1023) + (new_period * 100)) >> 10;

	//printf("s=%u c=%u err=%i period=%u period_max=%u\r\n", temp_set, temp_current, err, new_period, heater_max_period);

	// Re-arm adc trigger by setting the start bit
	adc_start_conversion_regular(ADC1);

	// Start the timer again
	timer_enable_counter(HEATER_TIMER);

	if (!kill_heater && new_period)
	{
		gpio_clear(GPIOB, GPIO_HEATER);
	}
}


void tim3_isr(void)
{
	// Only used for the OC interrupt
	// We should turn the heater OFF now
	timer_clear_flag(HEATER_TIMER, HEATER_TIMER_OC_IRQ);

	iwdg_reset();
	gpio_set(GPIOB, GPIO_HEATER);
}


static void tpf_putcf(void *ptr, char c)
{
	(void)ptr;
	usart_send_blocking(USART1, c);
}

static void clock_setup(void)
{
	rcc_clock_setup_in_hse_8mhz_out_48mhz();
	rcc_periph_clock_enable(RCC_GPIOA);
	rcc_periph_clock_enable(RCC_GPIOB);
	rcc_periph_clock_enable(RCC_USART1);
	rcc_periph_clock_enable(RCC_I2C1);
	rcc_periph_clock_enable(RCC_ADC1);
	rcc_periph_clock_enable(RCC_TIM3);
	rcc_periph_clock_enable(RCC_DMA);

	systick_set_frequency(1000, 48000000);
	systick_counter_enable();
	systick_interrupt_enable();
}


static void gpio_setup(void)
{
	// Timer output (On GPIOB !)
	// We do this first, since the heater is ON while the GPIO is floating!
	gpio_mode_setup(GPIOB, GPIO_MODE_OUTPUT, GPIO_PUPD_NONE, GPIO_HEATER);
	gpio_set_output_options(GPIOB, GPIO_OTYPE_PP, GPIO_OSPEED_HIGH, GPIO_HEATER);
	gpio_set(GPIOB, GPIO_HEATER);


	// USART
	gpio_mode_setup(GPIOA, GPIO_MODE_AF, GPIO_PUPD_NONE, GPIO2 | GPIO3);
	gpio_set_af(GPIOA, GPIO_AF1, GPIO2 | GPIO3);

	// I2C
	gpio_mode_setup(GPIOA, GPIO_MODE_AF, GPIO_PUPD_PULLUP, GPIO9 | GPIO10);
	gpio_set_output_options(GPIOA, GPIO_OTYPE_OD, GPIO_OSPEED_HIGH, GPIO9 | GPIO10);
	gpio_set_af(GPIOA, GPIO_AF4, GPIO9 | GPIO10);

	// ADC (V_TC and VDD)
	gpio_mode_setup(GPIOA, GPIO_MODE_ANALOG, GPIO_PUPD_NONE, GPIO0 | GPIO1);

	// Encoder and idle switch
	gpio_mode_setup(GPIOA, GPIO_MODE_INPUT, GPIO_PUPD_PULLUP, GPIO_ENCODER_A | GPIO_ENCODER_B | GPIO_ENCODER_SW | GPIO_IDLE_SW);
}


static void usart_setup(void)
{
	usart_set_baudrate(USART1, 115200);
	usart_set_databits(USART1, 8);
	usart_set_parity(USART1, USART_PARITY_NONE);
	usart_set_stopbits(USART1, USART_CR2_STOPBITS_1);
	usart_set_mode(USART1, USART_MODE_TX_RX);
	usart_set_flow_control(USART1, USART_FLOWCONTROL_NONE);

	usart_enable(USART1);
}


static void i2c_setup(void)
{
	rcc_set_i2c_clock_sysclk(I2C1);
	i2c_set_speed(I2C1, i2c_speed_fm_400k, 48);
	i2c_peripheral_enable(I2C1);
}


static void adc_setup(void)
{
	// The ADC will sample the TC voltage, VCC and the internal reference
	// TC conversion is last to maximize the time between turning off the heater and measuring the temp.
	// We configure the ADC in single-sequence mode tied to the haeter timer as trigger and the DMA in circular mode.
	// Then, a DMA_CPLT interrupt is generated after the full conversion is complete
	// To re-arm the ADC, we only need to set the start bit again.
	adc_calibrate(ADC1);
	adc_set_sample_time_on_all_channels(ADC1, ADC_SMPTIME_071DOT5);
	adc_enable_vrefint();
	uint8_t ADC_SEQUENCE[] = {ADC_CHANNEL_VREF, 1, 0};
	adc_set_regular_sequence(ADC1, sizeof(ADC_SEQUENCE) / sizeof(ADC_SEQUENCE[0]), ADC_SEQUENCE);
	adc_power_on(ADC1);
	adc_enable_dma(ADC1);
	adc_enable_external_trigger_regular(ADC1, ADC_TRIGGER, ADC_CFGR1_EXTEN_RISING_EDGE);
	//adc_enable_dma_circular_mode(ADC1);

	// setup DMA
	dma_set_memory_address(DMA1, DMA_CHANNEL1, (uint32_t)adc_values);
	dma_set_peripheral_address(DMA1, DMA_CHANNEL1, (uint32_t)&ADC1_DR);
	dma_set_memory_size(DMA1, DMA_CHANNEL1, DMA_CCR_MSIZE_16BIT);
	dma_set_peripheral_size(DMA1, DMA_CHANNEL1, DMA_CCR_PSIZE_16BIT);
	dma_enable_circular_mode(DMA1, DMA_CHANNEL1);
	dma_enable_memory_increment_mode(DMA1, DMA_CHANNEL1);
	dma_set_read_from_peripheral(DMA1, DMA_CHANNEL1);
	dma_enable_transfer_complete_interrupt(DMA1, DMA_CHANNEL1);
	dma_set_number_of_data(DMA1, DMA_CHANNEL1, sizeof(ADC_SEQUENCE) / sizeof(ADC_SEQUENCE[0]));
	dma_set_priority(DMA1, DMA_CHANNEL1, DMA_CCR_PL_HIGH);
	dma_set_channel_request(DMA1, DMA_CHANNEL1, 0);

	dma_enable_channel(DMA1, DMA_CHANNEL1);

	nvic_enable_irq(NVIC_DMA1_CHANNEL1_IRQ);

	// arm the adc trigger
	adc_start_conversion_regular(ADC1);
}


static void exti_setup(void)
{
	exti_select_source(EXTI_ENCODER_A | EXTI_ENCODER_SW | EXTI_IDLE_SW, GPIOA);
	exti_set_trigger(EXTI_ENCODER_A | EXTI_ENCODER_SW | EXTI_IDLE_SW, EXTI_TRIGGER_BOTH);
	exti_enable_request(EXTI_ENCODER_A | EXTI_ENCODER_SW | EXTI_IDLE_SW);

	nvic_enable_irq(NVIC_EXTI4_15_IRQ);
}


static void timer_setup(void)
{
	timer_set_mode(HEATER_TIMER, TIM_CR1_CKD_CK_INT, TIM_CR1_CMS_EDGE, TIM_CR1_DIR_UP);
	timer_set_prescaler(HEATER_TIMER, HEATER_TIMER_PRESCALER);
	timer_one_shot_mode(HEATER_TIMER);

	// for now we set the period to fixed 10ms
	timer_set_period(HEATER_TIMER, 10000);

	timer_set_master_mode(HEATER_TIMER, TIM_CR2_MMS_UPDATE);

	// instead of the OC output of the timer, we do it by foot through an interrupt
	// It's impossible to configure the OC output in a way, that the output stays in the same state as in the second half of the cycle
	timer_set_oc_value(HEATER_TIMER, HEATER_TIMER_OC, 0);
	timer_enable_irq(HEATER_TIMER, HEATER_TIMER_OC_IRQ);
	nvic_enable_irq(NVIC_TIM3_IRQ);
}


static void reset_stby_state(void)
{
	stby_state.timer = tickcounter;
	stby_state.idle_detect_timer = tickcounter;
	stby_state.idle_sw = input_idle_switch();
	stby_state.off = stby_state.manual_off;
	stby_state.stby = false;
}


static void update_stby_state(void)
{
	if (stby_state.manual_off)
	{
		stby_state.off = true;
		return;
	}

	if (!stby_state.off && config.idle_detect_threshold != 0)
	{
		// idle if long-term avg < current * (1 - threshold)
		if (current_duty_smoothed * (100 - config.idle_detect_threshold) > current_duty_lt_avg100)
		{
			// heater is doing things -> reset timer
			stby_state.idle_detect_timer = tickcounter;
		}
		else if (tickcounter - stby_state.idle_detect_timer > 60000UL * config.standby_time)
		{
			// idle detection timeout
			stby_state.off = true;
		}
	}

	if (input_idle_switch())
	{
		if (!stby_state.idle_sw)
		{
			stby_state.idle_sw = true;
			if (!stby_state.off)
			{
				// reset idle detect timer
				reset_stby_state();
			}
		}
		if (stby_state.off)
		{
			return;
		}

		if (stby_state.stby && tickcounter - stby_state.timer > 60000UL * config.standby_time)
		{
			// standby timeout -> turn off
			stby_state.off = true;
		}

		if (!stby_state.stby && tickcounter - stby_state.timer > 10000UL * config.standby_delay)
		{
			// not yet in standby and long enough in holder
			stby_state.stby = true;
			stby_state.timer = tickcounter;
		}
	}
	else
	{
		// NOT in holder
		if (stby_state.idle_sw)
		{
			// reset idle detect timer
			reset_stby_state();
		}
	}
}


static void update_config(void)
{
	timer_set_period(HEATER_TIMER, config.controller_period * 1000);
	heater_max_period = (((uint32_t)config.controller_max_pwm) * config.controller_period * 1000) / 100;

	if (temp_set < config.limit_min)
	{
		temp_set = config.limit_min;
	}
	if (temp_set > config.limit_max)
	{
		temp_set = config.limit_max;
	}

	config_save();
}


static bool outlier_detection(uint32_t value)
{
	// insert new value
	outlier_detection_sum -= outlier_detection_window[outlier_detection_index];
	outlier_detection_window[outlier_detection_index] = value;
	outlier_detection_index = (outlier_detection_index + 1) % OUTLIER_DETECTION_WND;
	outlier_detection_sum += value;

	uint32_t avg = outlier_detection_sum / OUTLIER_DETECTION_WND;

	uint32_t err_sum = 0;
	for (size_t i = 0; i < OUTLIER_DETECTION_WND; ++i)
	{
		if (outlier_detection_window[i] > avg)
		{
			err_sum += outlier_detection_window[i] - avg;
		}
		else
		{
			err_sum += avg - outlier_detection_window[i];
		}
	}

	uint32_t avg_err = err_sum / OUTLIER_DETECTION_WND;
	if (avg_err < OUTLIER_DETECTION_MIN_AVG_ERR)
	{
		avg_err = OUTLIER_DETECTION_MIN_AVG_ERR;
	}

	uint32_t val_err;
	if (value > avg)
	{
		val_err = value - avg;
	}
	else
	{
		val_err = avg - value;
	}

	return val_err * 100 < avg_err * OUTLIER_DETECTION_THRESHOLD;
}


static void screen_home(void)
{
	uint32_t sw_dn = 0;
	char disp_buf[32];
	uint32_t temp_changed_time;
	bool temp_changed = false;
	while (1)
	{
		uint16_t temp_round = (((temp_current1000 / 1000) + 2) / 5) * 5;
		//uint16_t temp_round = temp_current1000 / 1000;

		ssd1306_Fill(Black);
		ssd1306_SetCursor(0, 3);
		disp_buf[0] = ' ' + ((temp_round / 100) % 10);
		disp_buf[1] = ' ' + ((temp_round / 10 ) % 10);
		disp_buf[2] = ' ' + ((temp_round      ) % 10);
		disp_buf[3] = 0;

		ssd1306_WriteStringComp(disp_buf, CompFont_16x26_NUMC, White);
		ssd1306_DrawCircle(54, 10, 3, White);
		ssd1306_SetCursor(58,3);
		ssd1306_WriteStringComp("\x2a", CompFont_16x26_NUMC, White);

		ssd1306_SetCursor(90,3);
		snprintf(disp_buf, sizeof(disp_buf), "%3u", temp_set);
		ssd1306_WriteStringComp(disp_buf, CompFont_7x10, White);
		ssd1306_DrawCircle(117, 5, 1, White);
		ssd1306_SetCursor(121, 3);
		ssd1306_WriteStringComp("C", CompFont_7x10, White);

		if (kill_heater)
		{
			ssd1306_SetCursor(128 - 6 * 7,12);
			ssd1306_WriteStringComp("ERROR ", CompFont_7x10, Black);

			if (err_reason)
			{
				ssd1306_SetCursor(128 - 6 * 7,22);
				ssd1306_WriteStringComp(err_reason, CompFont_7x10, Black);
			}
		}
		else if (stby_state.off)
		{
			ssd1306_SetCursor(128 - 3 * 7,22);
			ssd1306_WriteStringComp("OFF", CompFont_7x10, White);
		}
		else if (stby_state.stby)
		{
			ssd1306_SetCursor(128 - 4 * 7,22);
			ssd1306_WriteStringComp("STBY", CompFont_7x10, White);
		}
		else
		{
			ssd1306_SetCursor(128 - 2 * 7,22);
			ssd1306_WriteStringComp("ON", CompFont_7x10, White);
		}

		uint16_t pwrline = current_duty_smoothed * 128 / heater_max_period;

		if (pwrline)
		{
			ssd1306_Line(0, 31, pwrline, 31, White);
		}

		ssd1306_UpdateScreen();


		printf("c=%lu, lt=%lu, idle=%lu\r\n", current_duty_smoothed, current_duty_lt_avg100, tickcounter - stby_state.idle_detect_timer);
		//printf("t_min=%i, tmax=%i, v33min=%i, v33max=%i\r\n", adc_tc_min, adc_tc_max, adc_v33_min, adc_v33_max);


		// update every 100 ms
		input_delay_or_evt(100);
		if (input_encoder_switch())
		{
			if (sw_dn == 0)
			{
				sw_dn = tickcounter;
			}
			else if (tickcounter - sw_dn > 1000)
			{
				// Long press -> Menu
				return;
			}
		}
		else if (sw_dn != 0)
		{
			sw_dn = 0;
			// Short press -> On/Off

			// We set the manual off state here to the inverse of the off state.
			// Otherwise (using the manual_state) pressing the switch while OFF from idle will turn the iron OFF first.
			stby_state.manual_off = !stby_state.off;
			reset_stby_state();
		}

		uint16_t old_temp = temp_set;
		temp_set = input_add_encoder_value_bound_step((temp_set * 5) / 5, config.limit_min, config.limit_max, 5);

		if (temp_set != old_temp)
		{
			temp_changed = true;
			temp_changed_time = tickcounter;
		}

		if (temp_changed && tickcounter - temp_changed_time > TEMP_SAVE_INTERVAL)
		{
			printf("Saving new temp: %u/r/n", temp_set);
			config_set_last_temperature(temp_set);
			temp_changed = false;
		}
	}
}


static void screen_raw(void)
{
	while (!input_encoder_switch())
	{
		uint32_t v33 = (3300 * ST_VREFINT_CAL) / adc_values[ADC_VALUE_VREF];
		uint32_t vdc = ((3300ULL * 11 * ST_VREFINT_CAL) * adc_values[ADC_VALUE_VDC]) / adc_values[ADC_VALUE_VREF] / 4096;
		uint32_t vtc = (((3300000ULL / (THERMOCOUPLE_GAIN)) * ST_VREFINT_CAL) * adc_values[ADC_VALUE_TC]) / adc_values[ADC_VALUE_VREF] / 4096;
		printf("v33=%lumV vdc=%lumV tc=%luuV ~temp=%luC\r\n", v33, vdc, vtc, vtc/8 + 25);

		char buff[32];
		ssd1306_Fill(Black);

		ssd1306_SetCursor(0,0);
		snprintf(buff, sizeof(buff), "V33 %4lu mV", v33);
		ssd1306_WriteStringComp(buff, CompFont_7x10, White);
		ssd1306_SetCursor(0,11);
		snprintf(buff, sizeof(buff), "VDC %4lu mV", vdc);
		ssd1306_WriteStringComp(buff, CompFont_7x10, White);
		ssd1306_SetCursor(0,22);
		snprintf(buff, sizeof(buff), "TC  %4lu uV", vtc);
		ssd1306_WriteStringComp(buff, CompFont_7x10, White);


		uint16_t pwr = current_duty_smoothed * 100 / heater_max_period;
		ssd1306_SetCursor(86,0);
		snprintf(buff, sizeof(buff), "P %u%%", pwr);
		ssd1306_WriteStringComp(buff, CompFont_7x10, White);

		ssd1306_UpdateScreen();
	}
}




int main(void)
{
	iwdg_set_period_ms(150);
	iwdg_start();

	clock_setup();
	gpio_setup();
	i2c_setup();
	exti_setup();
	usart_setup();
	adc_setup();
	timer_setup();

	init_printf(NULL, &tpf_putcf);

	printf("==============================================================\r\n");

	iwdg_reset();
	ssd1306_Init();

	input_init();

	// Don't turn on automatically as soon as there is power.
	stby_state.manual_off = true;
	reset_stby_state();

	iwdg_reset();

	temp_diff_panic_timer = tickcounter;

	// initially start the ADC sample sequence by starting the timer
	timer_enable_counter(HEATER_TIMER);

	// load config
	if (!config_load())
	{
		menu_restore_default_config();
	}

	temp_set = config_load_last_temperature();

	update_config();


	menu_result_t sel = menu_result_home;

	while (1)
	{
		printf("Show main screen %i\r\n", sel);
		switch (sel)
		{
			case menu_result_show_raw:
				screen_raw();
				break;

			case menu_result_home:
			default:
				screen_home();
				break;
		}

		sel = menu_main();
		update_config();
	}
}

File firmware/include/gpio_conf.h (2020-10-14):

#pragma once

#include <libopencm3/stm32/gpio.h>
#include <libopencm3/stm32/exti.h>

// GPIOA
#define GPIO_ENCODER_A  GPIO4
#define GPIO_ENCODER_B  GPIO5
#define GPIO_ENCODER_SW GPIO6
#define GPIO_IDLE_SW    GPIO7

// GBIOB
#define GPIO_HEATER     GPIO1

#define EXTI_ENCODER_A  EXTI4
#define EXTI_ENCODER_SW EXTI6
#define EXTI_IDLE_SW    EXTI7

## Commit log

2020-10-11 Added enclosure
    [case.scad]
2020-10-11 Added pcb
    [JBC_Nano_Hardware.kicad_pcb, JBC_Nano_Hardware.sch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]
2020-10-11 Fixed hardware issue (wrong mosfet)
    [JBC_Nano_Hardware.kicad_pcb, JBC_Nano_Hardware.sch]
2020-10-11 Added schematic as pdf
2020-10-11 added holder
    [case.scad]
2020-10-12 replaced window offset with integral component
    [main.c]
2020-10-14 better holder arm
    [case.scad]
2020-10-14 better behaviour of the power button
2020-10-15 added some more error triggers
    [main.c, menu.c]
2020-10-15 Added outlier detection for adc values
2020-10-15 Corrected value for TC sensitivity
    [main.c, menu.c]
2020-10-29 Improved holder arm
    [case.scad]
2021-01-04 Removed old fabrication output files (never wanted to commit those)
    [solder1-B_Cu.gbr, solder1-B_Mask.gbr, solder1-B_Paste.gbr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]
2021-12-20 Fixed initial config load triggering the watchdog
    [main.c]
2022-09-01 Cleaned schematic and updated to KiCad 6
    [JBC_Nano_Hardware.kicad_pcb, JBC_Nano_Hardware.kicad_sch]
2022-09-14 Fixed wrong resistor value for thermocouple gain
    [JBC_Nano_Hardware.kicad_sch]
